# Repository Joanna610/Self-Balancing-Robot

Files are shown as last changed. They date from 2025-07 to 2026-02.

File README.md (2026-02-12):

# Self_Balancing_Robot

This project is still in development !!!

The projects include code for Arduino. It collects data from the acceleromiter MPU6050 and modifies them accordingly. The code also turn on and off the motors with PWM. It can do this thanks to H bridge - L293D. The robot try to stabilize itself due to implemented PID algorithm.

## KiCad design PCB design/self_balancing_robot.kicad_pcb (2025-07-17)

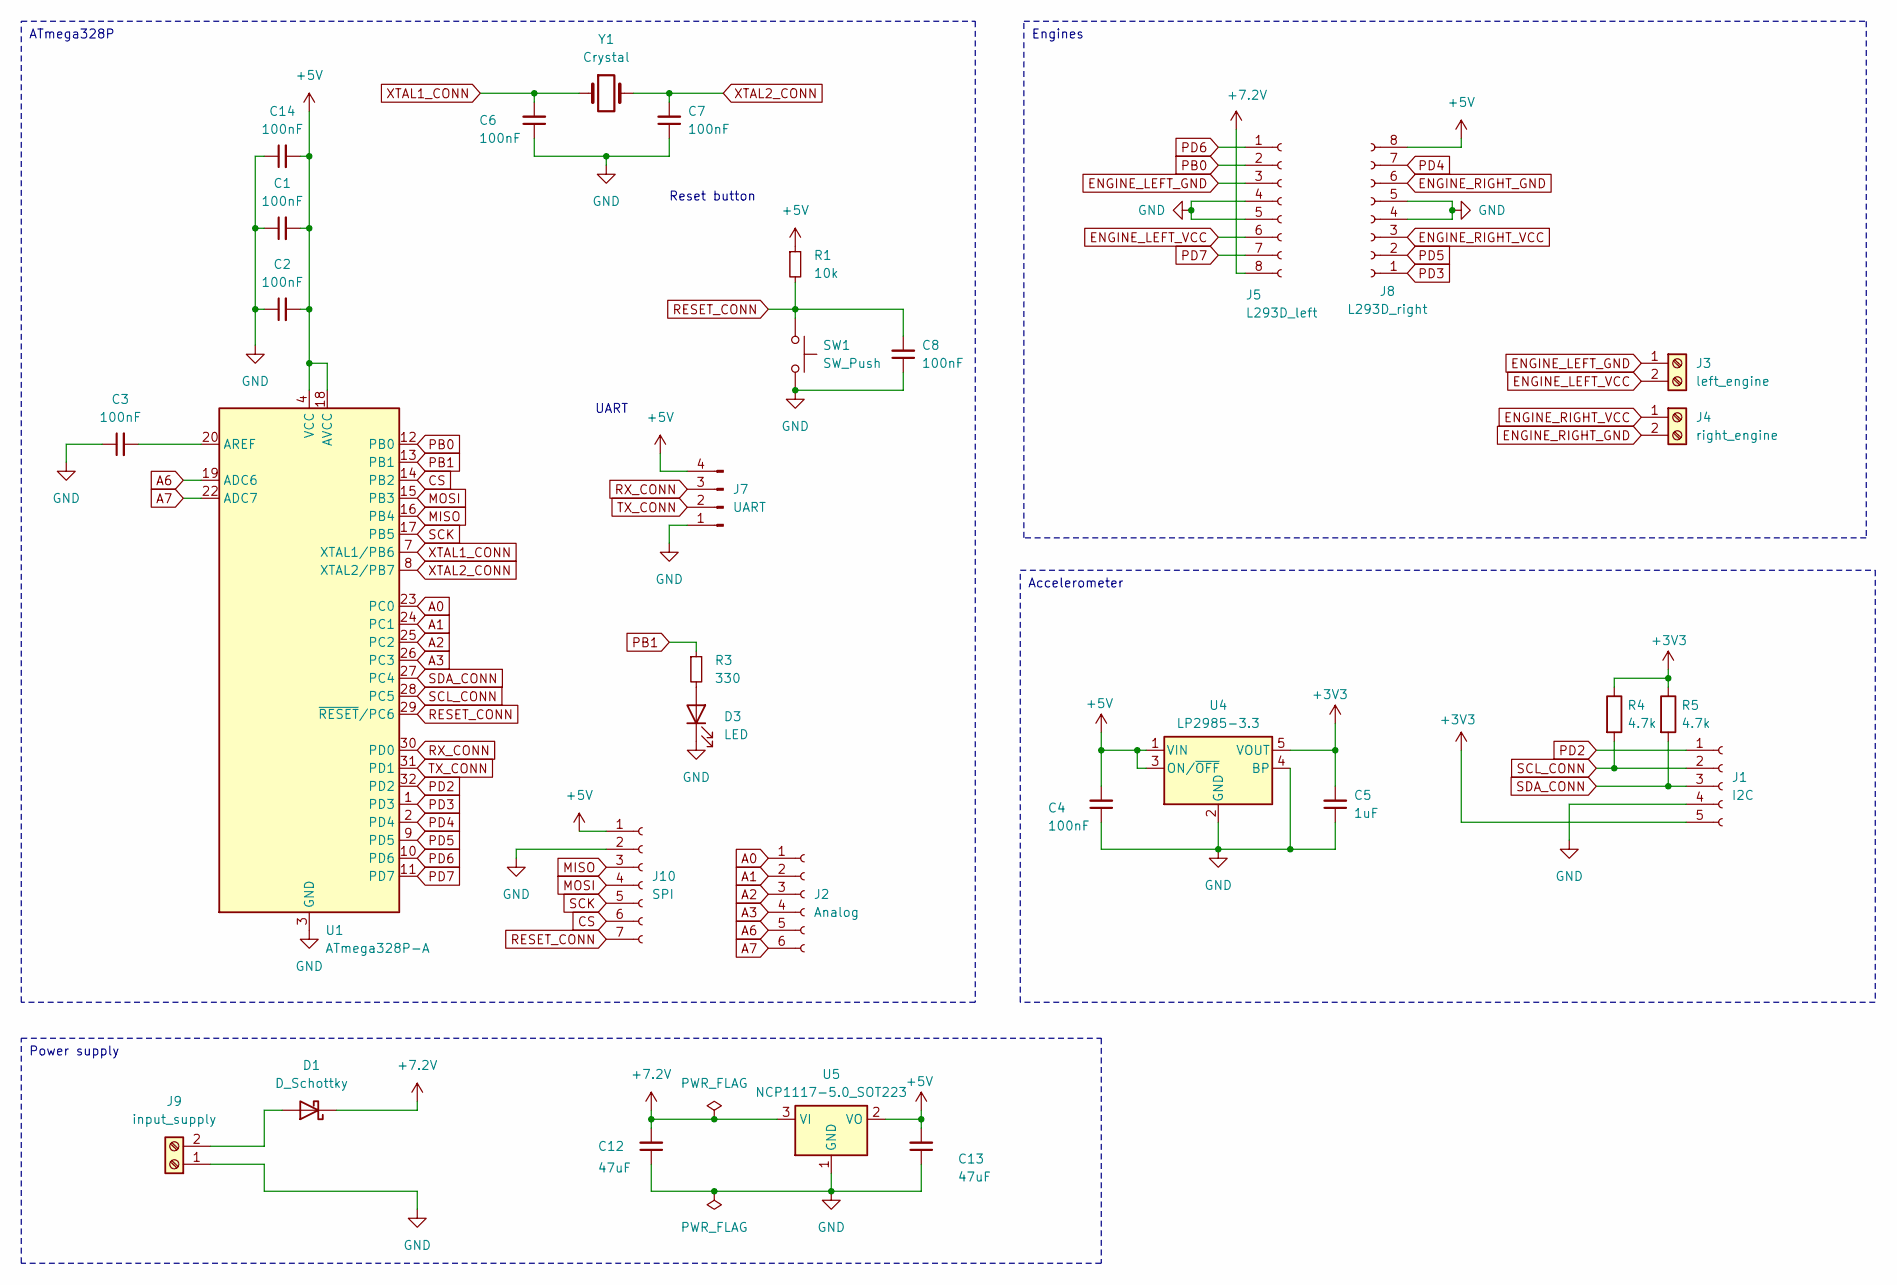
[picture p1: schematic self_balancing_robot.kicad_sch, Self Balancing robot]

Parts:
C1, C2, C3, C4, C6, C7, C8, C14: 100nF; C_0805_2012Metric
C5: 1uF; C_0805_2012Metric
C12, C13: 47uF; C_0805_2012Metric
D1: D_Schottky; R_Axial_DIN0207_L6.3mm_D2.5mm_P7.62mm_Horizontal
D3: LED; LED_1206_3216Metric
J1: I2C; PinSocket_1x05_P2.54mm_Vertical
J2: Analog; PinSocket_1x06_P2.54mm_Vertical
J3: left_engine; TE_826576-2_1x02_P3.96mm_Vertical
J4: right_engine; TE_826576-2_1x02_P3.96mm_Vertical
J5: L293D_left; PinSocket_1x08_P2.54mm_Vertical
J7: UART; PinHeader_1x04_P2.54mm_Vertical
J8: L293D_right; PinSocket_1x08_P2.54mm_Vertical
J9: input_supply; TE_826576-2_1x02_P3.96mm_Vertical
J10: SPI; PinSocket_1x07_P2.54mm_Vertical
R1: 10k; R_0805_2012Metric
R3: 330; R_0805_2012Metric
R4, R5: 4.7k; R_0805_2012Metric
SW1: SW_Push; SW_PUSH_1P1T_6x3.5mm_H5.0_APEM_MJTP1250
U1: ATmega328P-A; TQFP-32_7x7mm_P0.8mm
U4: LP2985-3.3; SOT-23-5
U5: NCP1117-5.0_SOT223; SOT-223-3_TabPin2
Y1: Crystal; Crystal_HC49-4H_Vertical

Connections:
+3V3: C5.2, J1.5, R4.1, R5.1, U4.5 (VOUT)
+5V: C1.2, C2.2, C4.2, C13.2, C14.2, J7.4, J8.8, J10.1, R1.1, U1.4 (VCC), U1.6 (VCC), U1.18 (AVCC), U4.1 (VIN), U4.3 (ON/~OFF), U5.2 (VO)
+7.2V: C12.2, D1.1 (K), J5.8, U5.3 (VI)
A0: J2.1, U1.23 (PC0)
A1: J2.2, U1.24 (PC1)
A2: J2.3, U1.25 (PC2)
A3: J2.4, U1.26 (PC3)
A6: J2.5, U1.19 (ADC6)
A7: J2.6, U1.22 (ADC7)
CS: J10.6, U1.14 (PB2)
ENGINE_LEFT_GND: J3.1, J5.3
ENGINE_LEFT_VCC: J3.2, J5.6
ENGINE_RIGHT_GND: J4.2, J8.6
ENGINE_RIGHT_VCC: J4.1, J8.3
GND: C1.1, C2.1, C3.1, C4.1, C5.1, C6.1, C7.1, C8.1, C12.1, C13.1, C14.1, D3.1 (K), J1.4, J5.4, J5.5, J7.1, J8.4, J8.5, J9.1, J10.2, SW1.2, U1.3 (GND), U1.5 (GND), U1.21 (GND), U4.2 (GND), U4.4 (BP), U5.1 (GND)
MISO: J10.3, U1.16 (PB4)
MOSI: J10.4, U1.15 (PB3)
unnamed: D1.2 (A), J9.2
unnamed: D3.2 (A), R3.2
unnamed: C3.2, U1.20 (AREF)
PB0: J5.2, U1.12 (PB0)
PB1: R3.1, U1.13 (PB1)
PD2: J1.1, U1.32 (PD2)
PD3: J8.1, U1.1 (PD3)
PD4: J8.7, U1.2 (PD4)
PD5: J8.2, U1.9 (PD5)
PD6: J5.1, U1.10 (PD6)
PD7: J5.7, U1.11 (PD7)
RESET_CONN: C8.2, J10.7, R1.2, SW1.1, U1.29 (~RESET/PC6)
RX_CONN: J7.3, U1.30 (PD0)
SCK: J10.5, U1.17 (PB5)
SCL_CONN: J1.2, R4.2, U1.28 (PC5)
SDA_CONN: J1.3, R5.2, U1.27 (PC4)
TX_CONN: J7.2, U1.31 (PD1)
XTAL1_CONN: C6.2, U1.7 (XTAL1/PB6), Y1.1
XTAL2_CONN: C7.2, U1.8 (XTAL2/PB7), Y1.2

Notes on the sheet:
Engines
ATmega328P
Accelerometer
Power supply
UART
Reset button

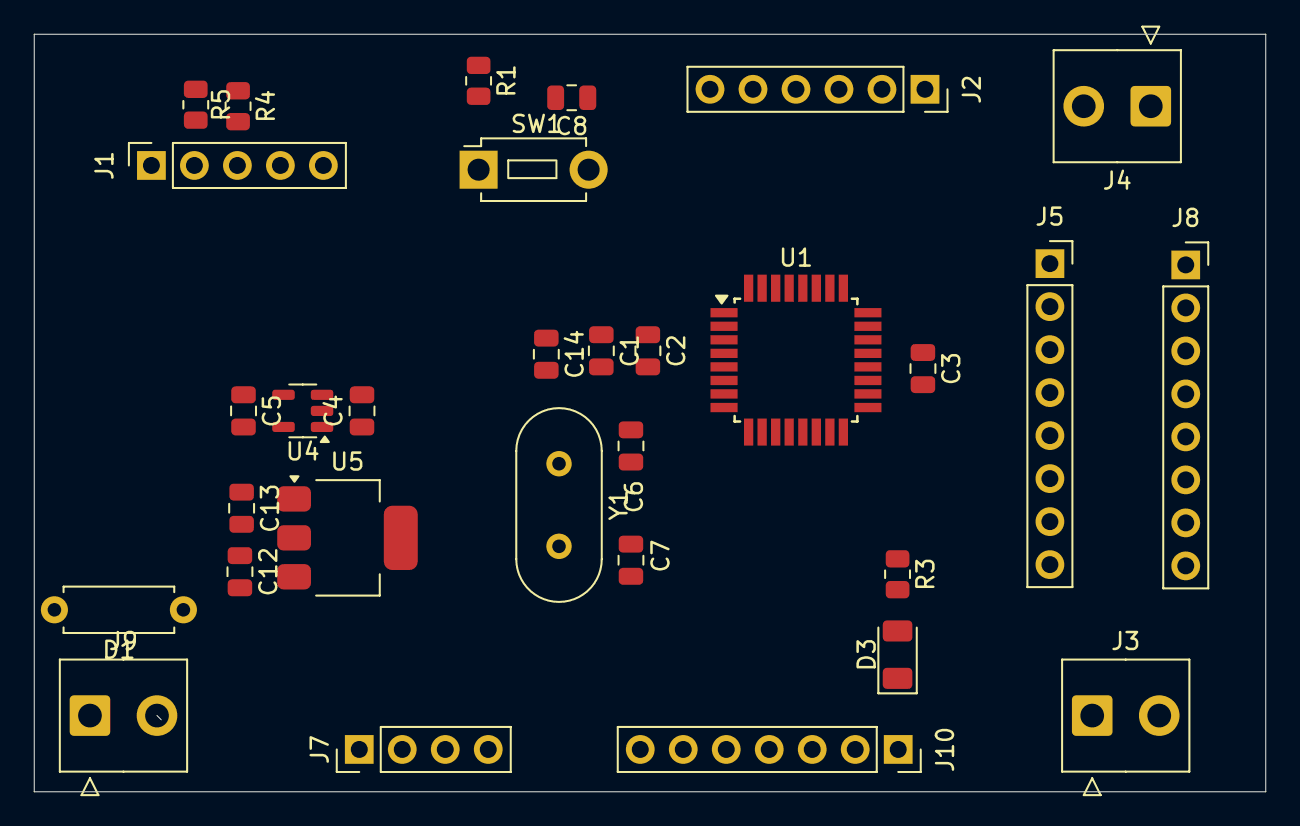
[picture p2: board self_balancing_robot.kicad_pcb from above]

Board: 2 copper layers, 72.8 x 44.8 mm, 31 parts (0 on the bottom side), 36 nets.
